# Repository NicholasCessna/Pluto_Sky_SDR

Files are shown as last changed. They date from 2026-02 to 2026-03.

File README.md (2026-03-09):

I made this repo in hope of sharing some projects I plan to work on with this board including some other files I may create such as the Case for 3D printing and a future Android Application. I also welcome as much interaction here 
as possible from the SDR community. Resources on the Pluto Sky in particular are scarce though it seems compatible with software that supports the original Analog Device Pluto device. 

__________________________________________________________________________________________________________________________

***GENERAL DISCLAIMERS: For now and future***

This software is for educational and research purposes only. The user is solely responsible for complying with all local laws and regulations, including those set by the FCC or equivalent authorities in your jurisdiction. 
The author(s) assume no liability for any unauthorized use or any damages resulting from the use of this software.

This repos contents are distributed in the hope that it will be useful, but WITHOUT ANY WARRANTY; without even the implied warranty of MERCHANTABILITY or FITNESS FOR A PARTICULAR PURPOSE. Use at your own risk.

Transmitting radio signals without a proper license is illegal in many countries. Any actions taken using this code are at your own discretion and risk. I am not responsible for any fines, equipment damage, or legal consequences incurred.

In no event unless required by applicable law or agreed to in writing will any copyright holder, or any other party who may modify and/or redistribute the program or other materials as permitted above, be liable to you for damages, including any general, special, incidental or consequential damages arising out of the use or inability to use the program (including but not limited to loss of data or data being rendered inaccurate or losses sustained by you or third parties or a failure of the program to operate with any other programs), even if such holder or other party has been advised of the possibility of such damages.

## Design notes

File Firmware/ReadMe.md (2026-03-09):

I have additional firmware given in a package I received with the board. The other firmware package is quite large for Github upload standards so if you're interested please reach out.

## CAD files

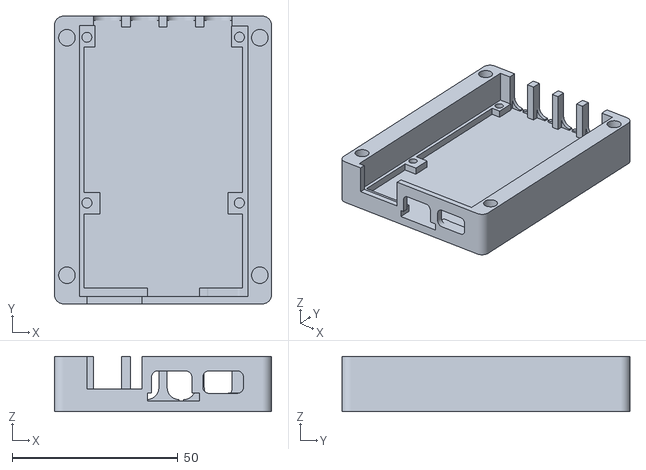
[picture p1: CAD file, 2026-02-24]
Case_3D_Print_STLs/Pluto_Sky_Case_Bottom.stl
65.5 x 86.9 x 16.7

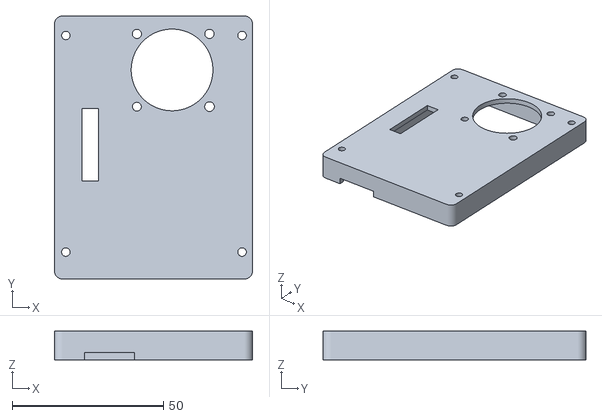
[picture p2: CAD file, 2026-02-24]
Case_3D_Print_STLs/Pluto_Sky_Case_Top.stl
65.5 x 86.9 x 9.50

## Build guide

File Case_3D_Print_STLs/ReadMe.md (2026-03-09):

Please ensure this is the same board. I originally made a case from a STEP of the board I found online and upon getting the board realized it was not the exact same hardware layout 
(few few mm here and there of difference) and was a different revision so I had to make revisions to the cases design. The board in which I designed the case around is from Open Source SDR Labs entitled 
"OpenSourceSDRLab New 7020-SDR AD9361 Development Board with PA" bought in 2026. A few comments about the 3D print files.

1) The design requires various hardware to anchor the board to the base and to fix the top and bottom together. I used threaded inserts to allow for easy mounting and connection.
2) For board mounting, you will need 4x M2 * 2 * 3 threaded inserts and 4 corresponding M2 * 4 bolts.
3) For connecting the top and bottom of the case you will need 4x M3 * 5 * 5 threaded inserts and 4 M3 * 6 bolts
4) Finally, I included cut-outs in the top for a fan. The fan I used was bought from amazon and was intended for a RPI 3B but worked nicely. The hardware that came with the fans (it was a 2 pack) also worked
   nicely. If you are interested or want reference they can be found at the following link. https://a.co/d/0dxboW4R
   The dim of the fan is 30mm x 30mm x 7mm.
   NOTE: One adjustment I made to the fan was replacing the gpio pin connectors with the matching JST 1.25 mm connector. (I had this laying around so I cant provide a direct link but I
   would say the connector at the following link would be a good lead to finding what you might need: https://www.digikey.com/short/j9b2vf02... ADDITIONALLY if you want to buy a 30 mm x 30 mm fan with
   this connector and skip the soldering my eye (and a little research) tells me this would be what you want: https://www.digikey.com/short/thf97fhz

NOTE: If you have never used 3D Inserts in your 3D prints you will need a soldering Iron to press them into place. The inserts I used came from a kit sold on amazon at : https://a.co/d/07en3sjy
also these are not affiliate links, just to be helpful.

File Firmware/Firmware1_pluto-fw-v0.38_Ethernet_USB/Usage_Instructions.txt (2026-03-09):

1) Format the SD card to FAT32 format and copy the files from the SD card firmware into the SD card.

2) Insert the SD card into the SD card slot, set the dip switch to SD card boot mode, insert the Ethernet cable (or USB cable), and power on.

3) If using USB communication, you need to install the USB virtual network card driver in advance. Once installed, the official upper-level machine can be used in normal mode.

4) If using the Ethernet port, you need to set the IP address. Also, plug in the USB for the JTAG port. The default login credentials for the firmware are: username: root, password: analog. Then, configure the IP address using the command: ifconfig eth0 192.168.1.xx. Once done, the official upper-level machine can be used in normal mode.

5) Be mindful of the board's heat dissipation. For long-term operation, a CNC heat sink or fan is recommended. Thank you for your understanding!

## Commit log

2026-02-24 Update ReadMe with hardware layout case information
    Added important notes about hardware compatibility and revisions.
2026-02-24 Update ReadMe with hardware and fan details
    Added detailed instructions for hardware requirements and fan specifications for the 3D printed case.
2026-03-09 Fix typos and enhance clarity in ReadMe.md
    Corrected typos and improved clarity in the README regarding the board case design and hardware requirements.
